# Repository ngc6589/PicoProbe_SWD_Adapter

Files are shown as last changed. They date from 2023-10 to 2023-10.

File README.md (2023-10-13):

# Raspberry Pi Pico SWD Debugger

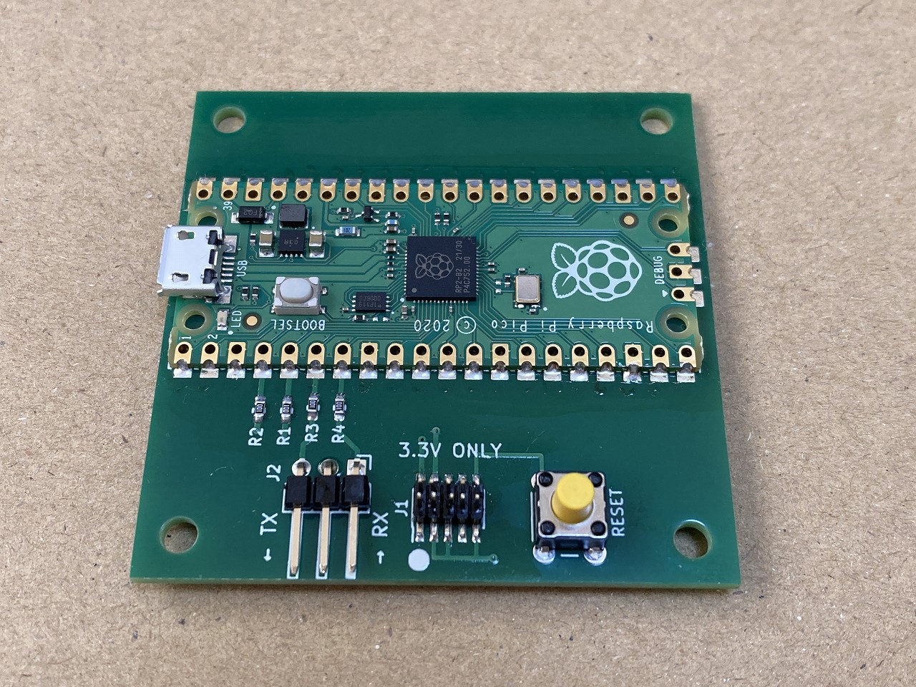
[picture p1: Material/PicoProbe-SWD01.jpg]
expansionBoard


# この基板について

PicoProbe という SWD デバッガにハーフピッチの 2x5 10pin ヘッダをつけた基板です。
SWDIO と SWCLK の 2線でデバッグするデバッガとなります。 opnocd -f interface/cmsis-dap.cfg で使用可能なデバッガですので汎用タイプになります。
ただし、<font color="red"><b>ターゲットの電圧は 3.3V 固定</b></font> となります。

基本的には 下記リンクにある NXP社の MCU-Link, MCU-Link Pro をお勧めします。数年前まで秋月などで安く購入出来た NXP LPC-Link2 の後継です。これでしたら、ターゲットの電圧 1.2V - 5V 対応です。

 [MCU-Link Debug Probe](https://www.nxp.jp/design/software/development-software/mcuxpresso-software-and-tools-/mcu-link-debug-probe:MCU-LINK)

[MCU-Link Pro Debug Probe](https://www.nxp.jp/design/software/development-software/mcuxpresso-software-and-tools-/mcu-link-pro-debug-probe:MCU-LINK-PRO)

当基板は、基本的には SWD デバッガの相性問題などで別のデバッガを試してみたいなどにご利用ください。

<b>ターゲットプロセッサやホスト OS、openocd のバージョンや openocd のコンフィグファイルなどの設定内容によって相性問題はかなりの確率で発生すると思われます。相性問題に伴う保証はできません。</b> MCU-Link もお勧めはしていますが、これも全ての環境で完璧に動くわけでも無いため同様に保証することはできません。

# 使用法

## 準備
基基板に USB ケーブルを接続し PC に接続してください。

■Windows 

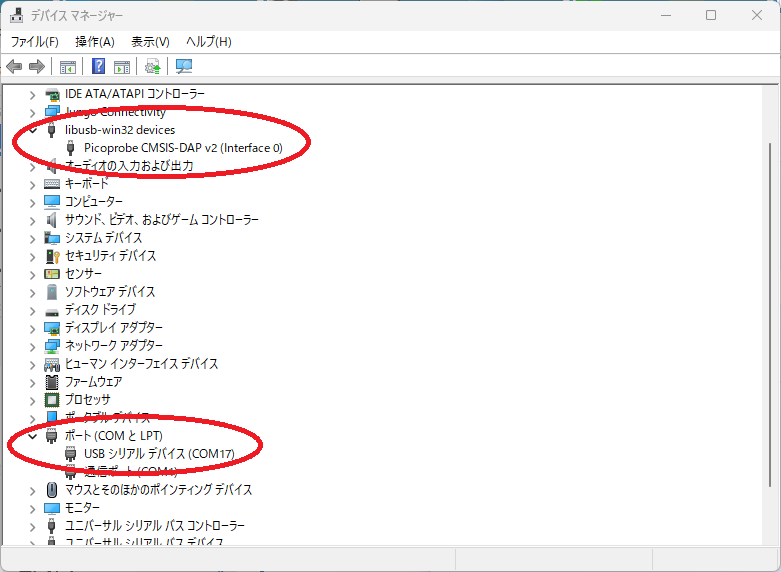
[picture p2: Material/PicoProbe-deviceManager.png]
DeviceManager


CMSIS-DAP インタフェースが libusb-win32 に、シリアルポートがポート(COMとLPT)に表示されたら問題ありません。

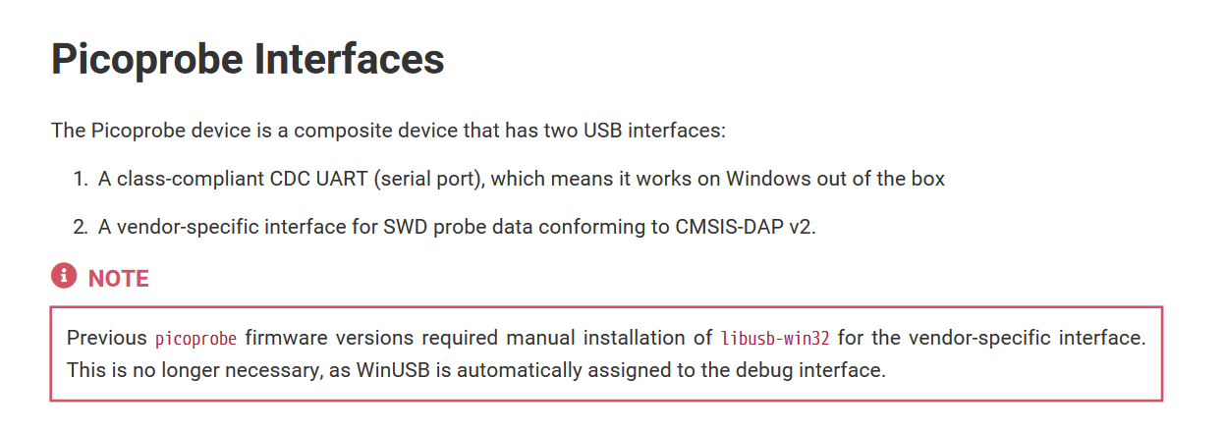
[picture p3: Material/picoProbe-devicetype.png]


ただし、Getting Start マニュアルには以前は libusb-win32 が必要だったけど、今はいい。とあるので、WinUSB で認識されていても問題ないと重います。最新 PicoProbe のファームウエア picoprobe-cmsis-v1.0.3 は libusb-win32 でも動いています。

現状 CMSIS-DAP が見えていたら動くと思われます。動かない場合は zadig コマンドをネットからダウンロードして、CMSIS-DAP のドライバを切り替えばいいです。

■Linux の場合は、openocd にある udev の .rules ファイルを /etc/udev/rules.d にコピーして
```
$ sudo udevadm control --reload-rules
$ sudo udevadm trigger
```

あとは、シリアルポートをユーザーが使えるように dialout グループにユーザー追加します。
```
$ sudo usermod -aG dialout ユーザー名
```

デバッグプローブを USB に挿して、/var/log/syslog に probe の CMSIS-DAP 名や、シリアルポートが ttyUSB0 などにアタッチされたメッセージがでていれば問題ありません。

# 結線

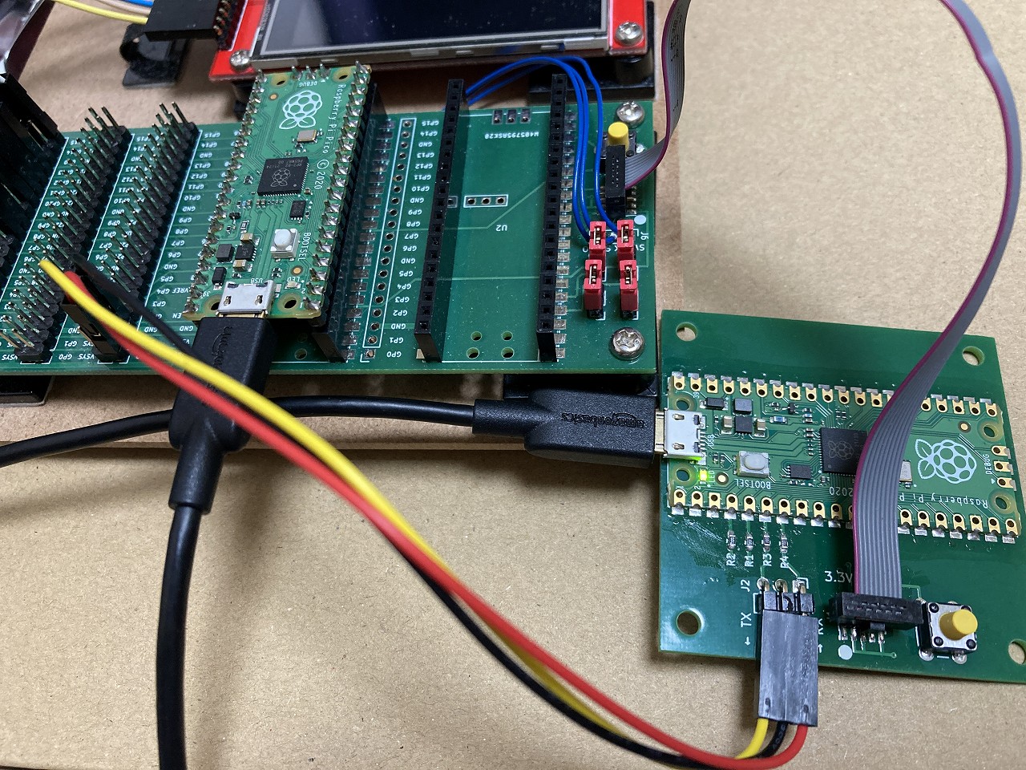
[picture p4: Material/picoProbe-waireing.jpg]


PicoProbe 基板とターゲットの基板をフラットケーブルで接続します。uart を使用する場合は、Lアングルのピンヘッダにマイコンの TX/RX を接続してください。

# vscode 表示例

「実行」「デバッグの開始」を選択してデバッグを開始します。openocd・gdb-multiarch が問題なく起動できれば、プログラムがターゲットに書き込まれてデバッグが始まります。
↓のスクリーンショットのように変数が表示されたりしていればデバッガは動いています。また、プログラムのプリント出力も、vscode のシリアルモニタに表示されていれば問題はありません。

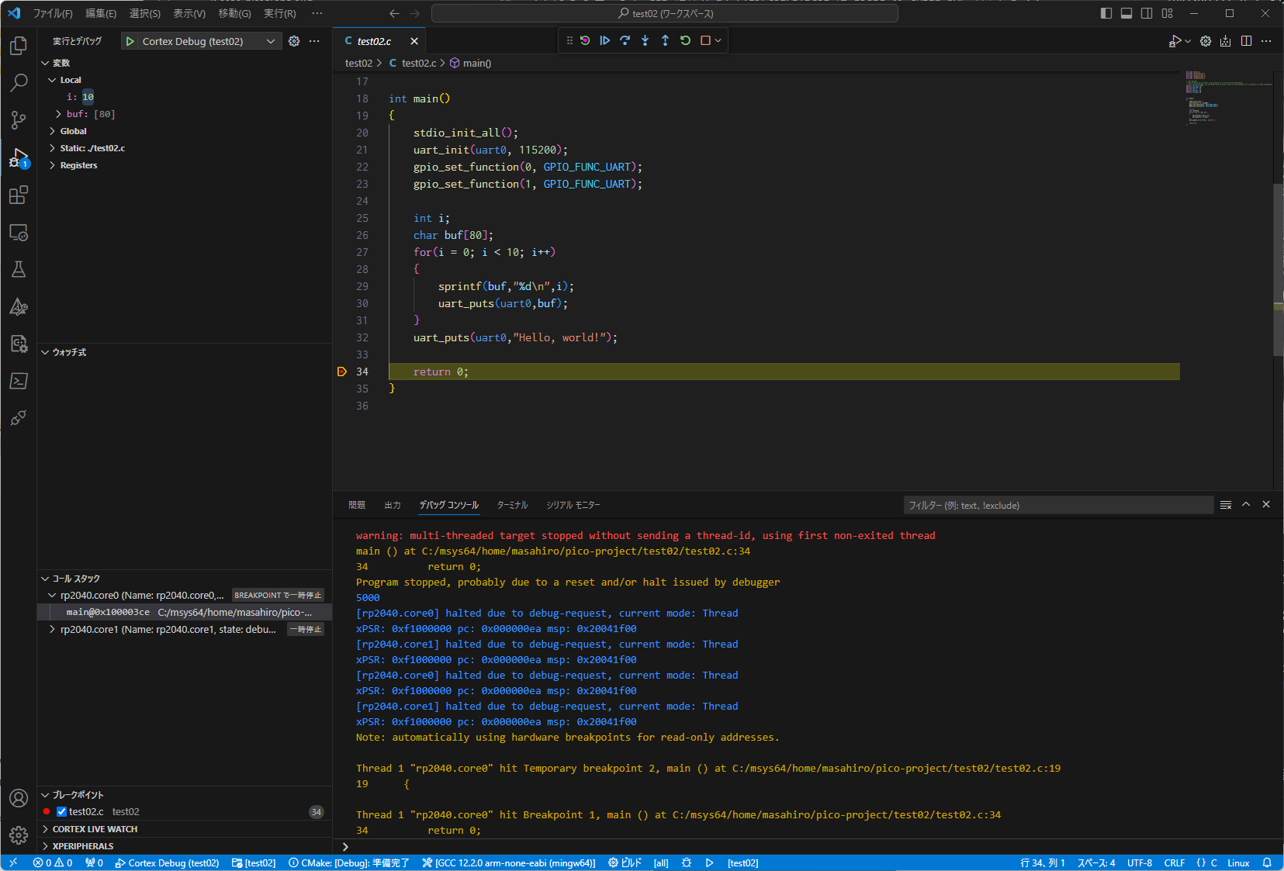
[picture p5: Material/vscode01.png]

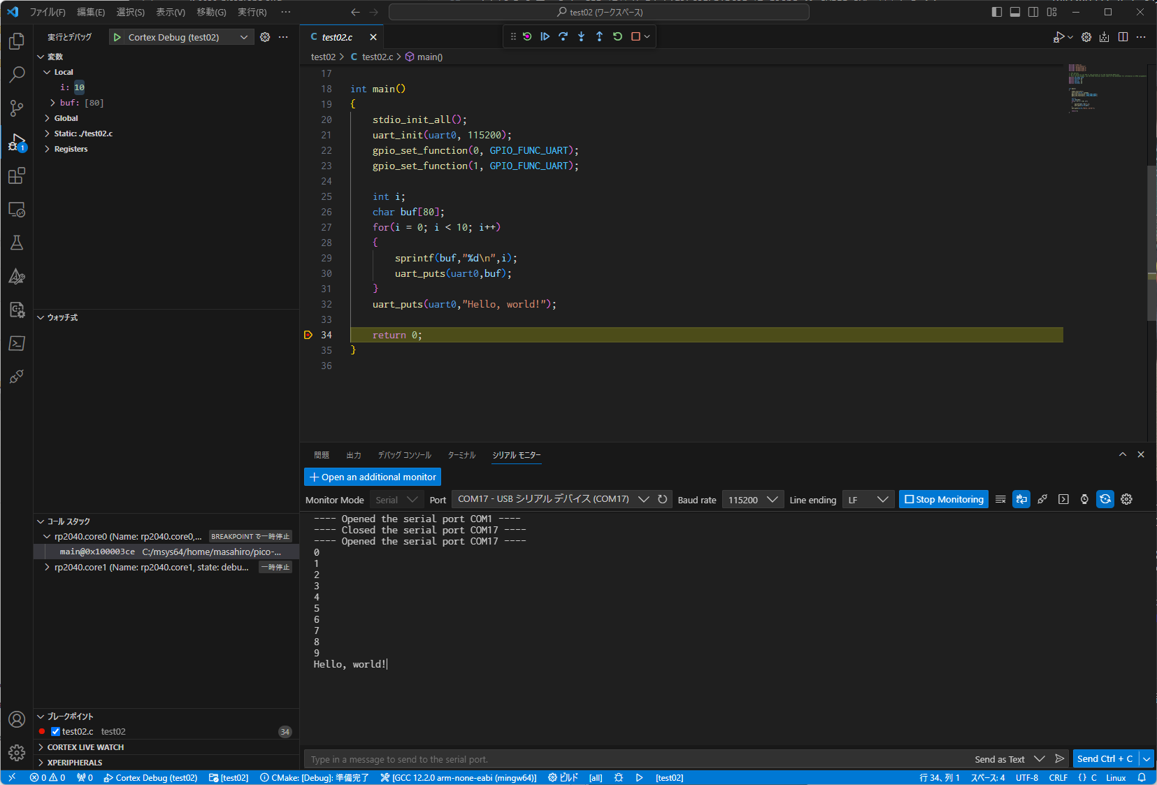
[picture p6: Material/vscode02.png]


# 回路図・ガーバーファイル
回路図は Schematic.pdf を参照してください。  
ガーバーファイルは KiCad/20231007 フォルダを参照してください。

# 部品表

上記組み立て例の部品表は以下のようになります。

|部品番号|部品名|数量|通販アドレス|備考|
|---|---|---|---|---|
|U1|Raspberry Pi Pico|1|https://akizukidenshi.com/catalog/g/gM-16132/||
|J1|ピンヘッダ　２×５（１０Ｐ）　表面実装用　１．２７ｍｍピッチ|1|https://akizukidenshi.com/catalog/g/gC-10904/||
|J2|ピンヘッダ　Ｌ型　１×３　（３Ｐ）|1|https://akizukidenshi.com/catalog/g/gC-15510/||
|SW1|タクトスイッチ|1|https://akizukidenshi.com/catalog/g/gP-03650/|リンクは黄色の例|
|R1-R4|10Ω 0603(1608)|4|||
||２×５（１０Ｐ）両端コネクタ付ＩＤＣリボンケーブル（フラットケーブル　ハーフピッチ）|1|https://akizukidenshi.com/catalog/g/gC-06776/|||
||プリント基板|1||||

# 引用
Raspberry Pi PICO の KiCad ライブラリは https://github.com/ncarandini/KiCad-RP-Pico を利用しています。

PicoProbe は、https://github.com/raspberrypi/picoprobe の公式ファームウエアを使用しています。

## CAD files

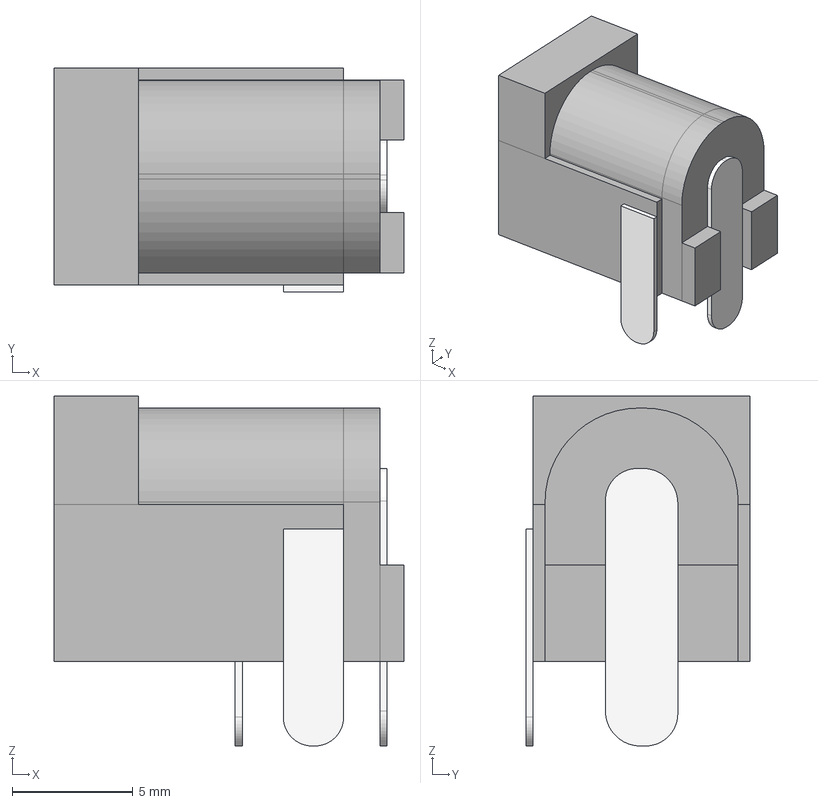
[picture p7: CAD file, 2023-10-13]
KiCad/_LocalLibraries/MJ-179PH-Part.step
14.5 x 9.30 x 14.5 mm

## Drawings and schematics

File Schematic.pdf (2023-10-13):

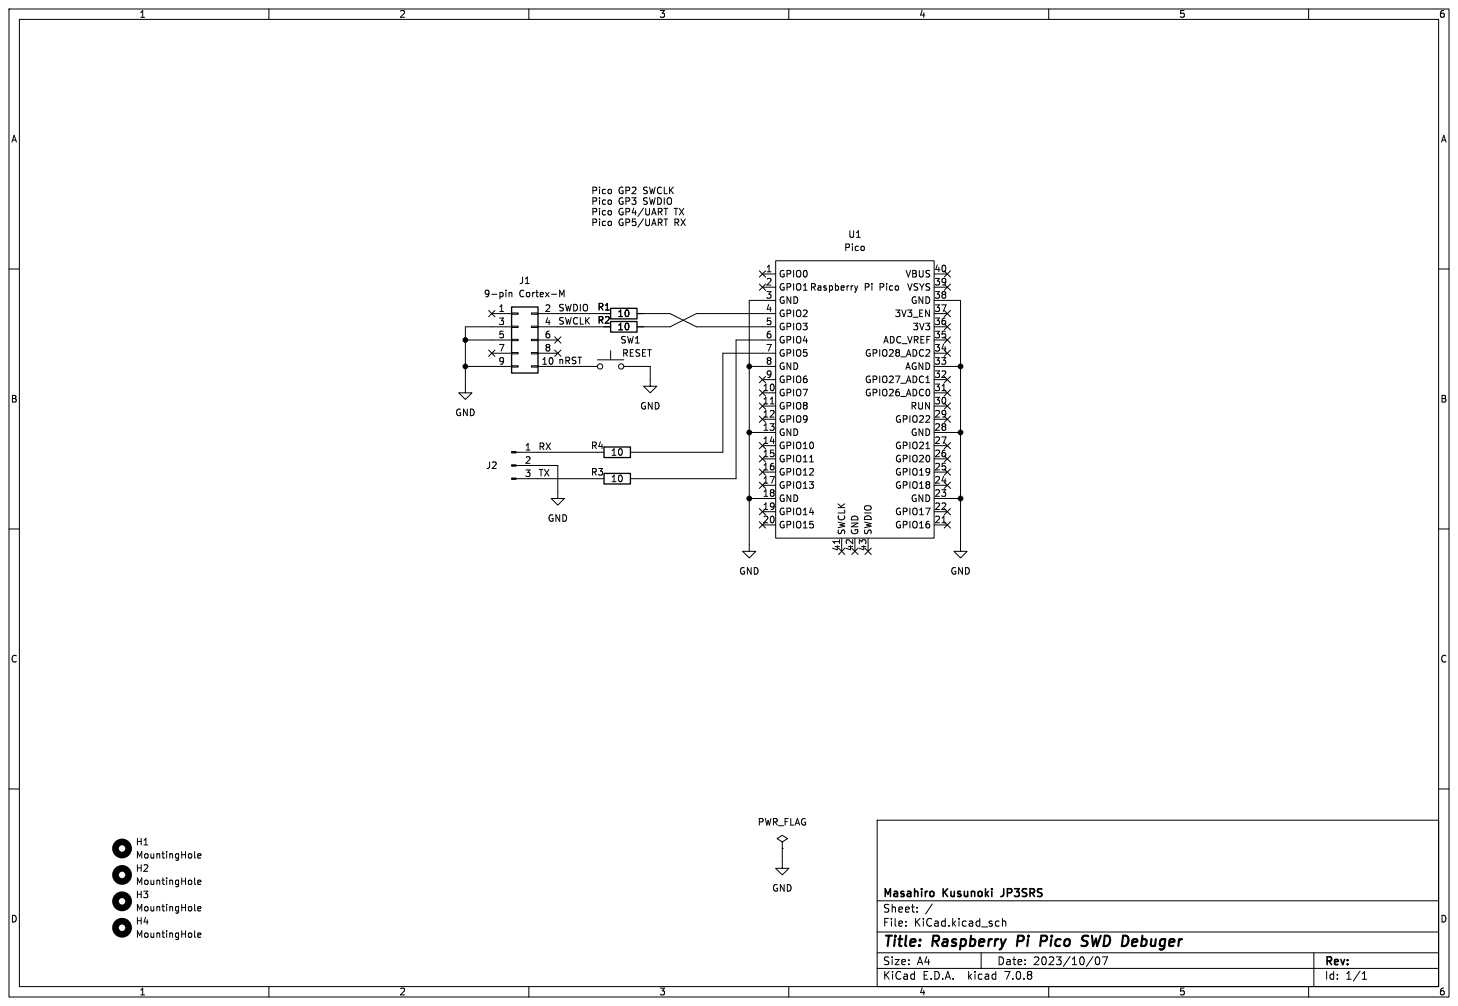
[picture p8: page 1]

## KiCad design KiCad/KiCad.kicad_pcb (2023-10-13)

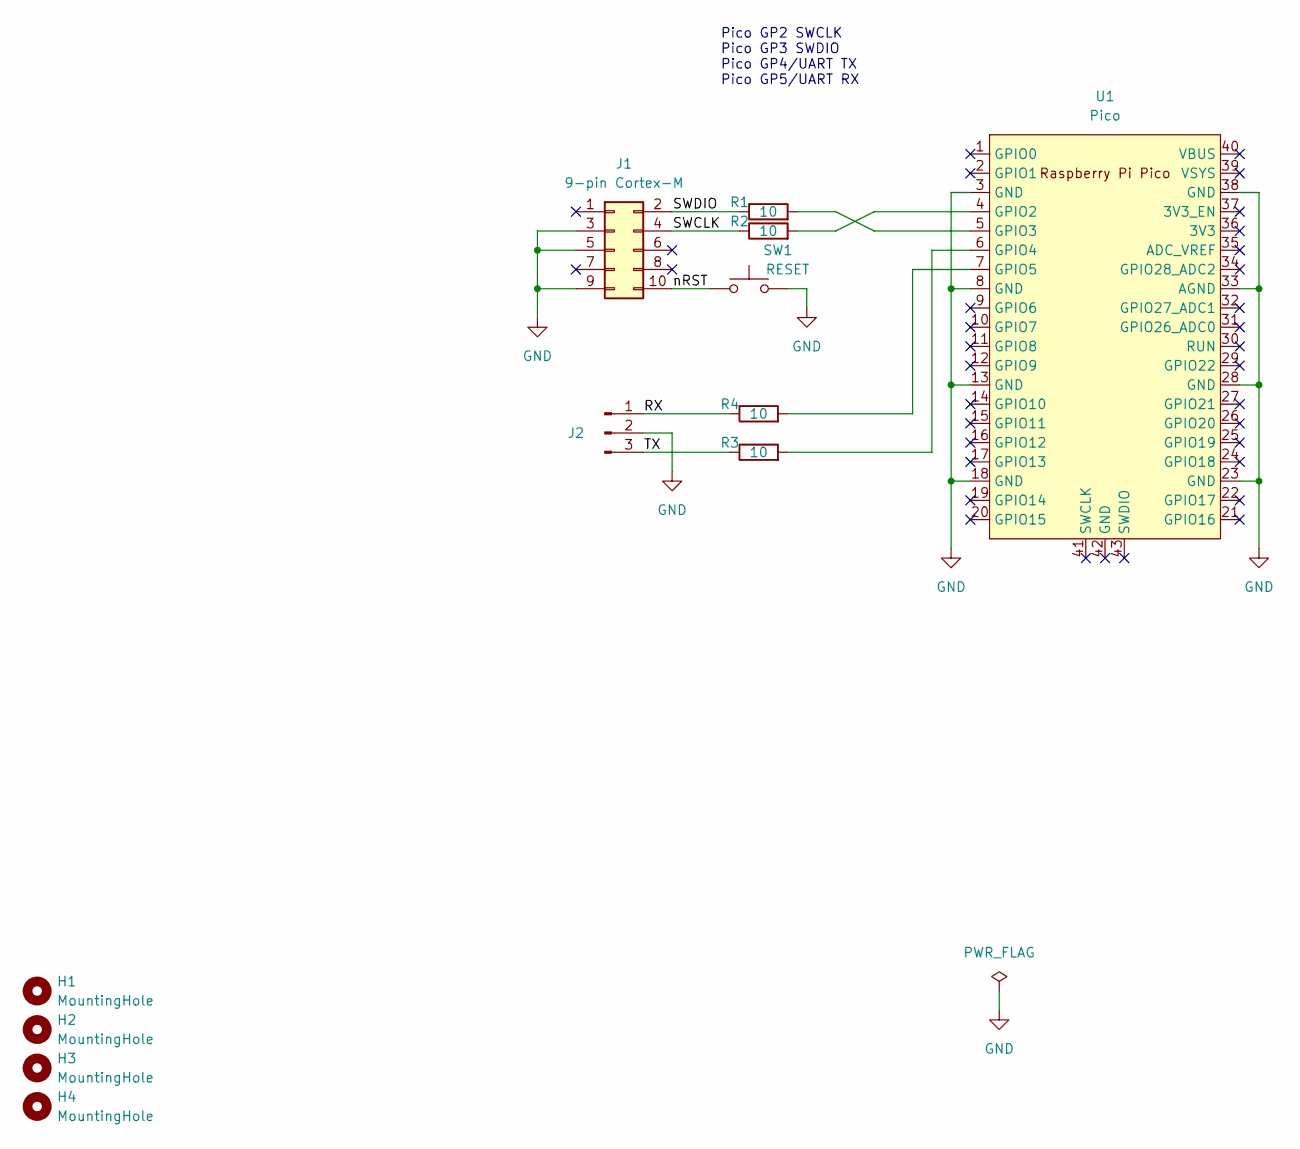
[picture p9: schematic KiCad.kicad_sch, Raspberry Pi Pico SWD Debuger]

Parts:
H1, H2, H3, H4: MountingHole; MountingHole_3.2mm_M3
J1: 9-pin Cortex-M; PinHeader_2x05_P1.27mm_Vertical_SMD
J2: Conn_01x03_Pin; PinHeader_1x03_P2.54mm_Horizontal
R1, R2, R3, R4: 10; R_0603_1608Metric_Pad0.98x0.95mm_HandSolder
SW1: RESET; SW_PUSH_6mm
U1: Pico; RPi_Pico_SMD_TH

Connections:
/RX: J2.1, R4.1
/SWCLK: J1.4, R2.1
/SWDIO: J1.2, R1.1
/TX: J2.3, R3.1
/nRST: J1.10, SW1.1
GND: J1.3, J1.5, J1.9, J2.2, SW1.2, U1.3 (GND), U1.8 (GND), U1.13 (GND), U1.18 (GND), U1.23 (GND), U1.28 (GND), U1.33 (AGND), U1.38 (GND)
unnamed: R2.2, U1.4 (GPIO2)
unnamed: R1.2, U1.5 (GPIO3)
unnamed: R3.2, U1.6 (GPIO4)
unnamed: R4.2, U1.7 (GPIO5)

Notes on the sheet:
Pico GP2 SWCLK Pico GP3 SWDIO Pico GP4/UART TX Pico GP5/UART RX

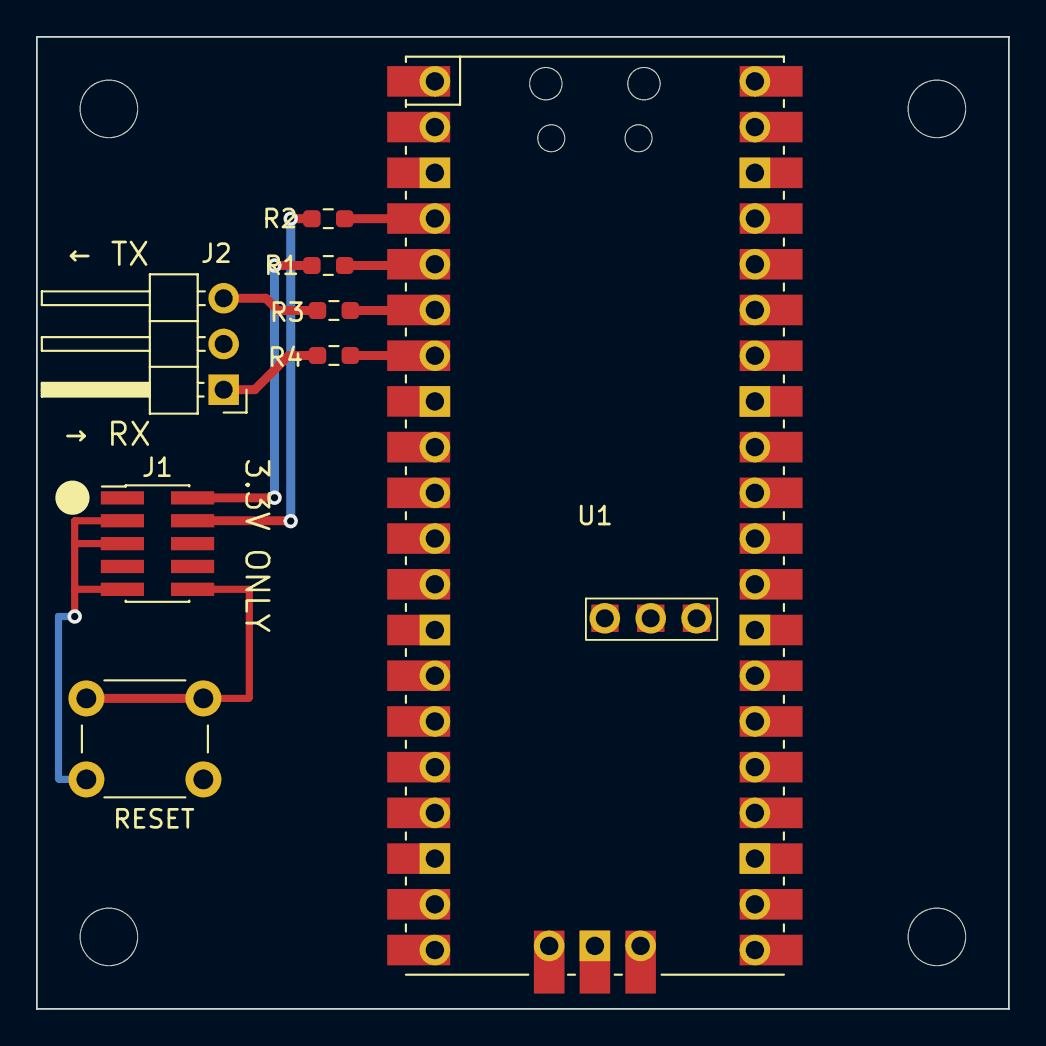
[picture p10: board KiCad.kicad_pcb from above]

Board: 2 copper layers, 54.0 x 54.0 mm, 12 parts (0 on the bottom side), 10 nets.

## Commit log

2023-10-13 ADD NEW FILES
    [KiCad-B_Cu.gbr, KiCad-B_Mask.gbr, KiCad-B_Paste.gbr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]
2023-10-13 ADD MATERIAL FOLDER
